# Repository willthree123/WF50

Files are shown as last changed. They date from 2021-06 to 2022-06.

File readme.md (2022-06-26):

# WF50

WF50 is a 50-keys split keyboard.

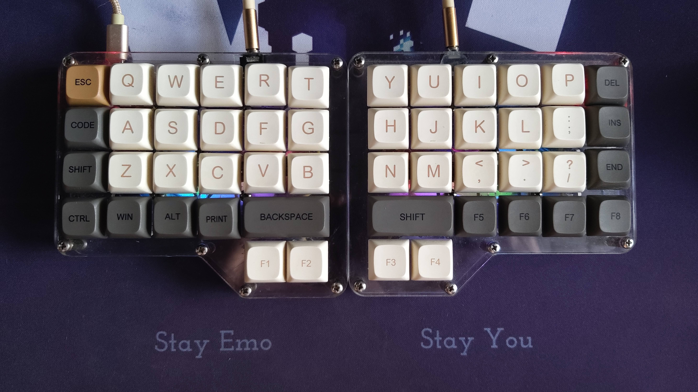
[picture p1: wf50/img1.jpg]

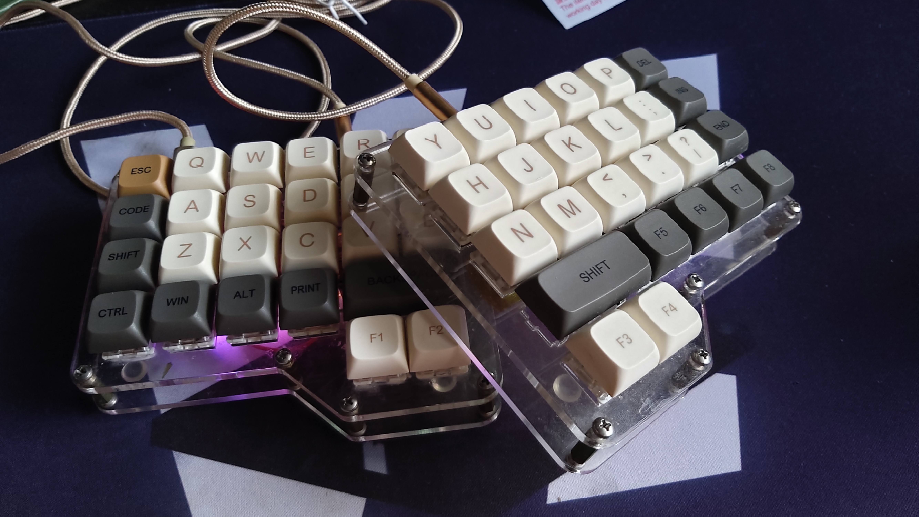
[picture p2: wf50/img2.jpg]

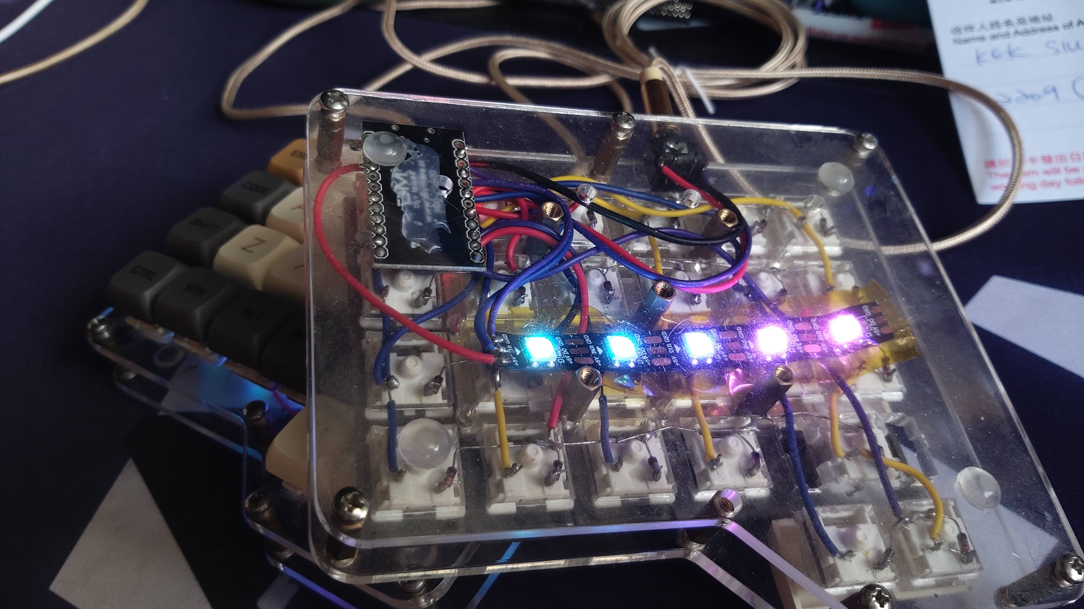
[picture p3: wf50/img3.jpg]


Keyboard Maintainer: [willthree123](https://github.com/willthree123/) Instagram: [@kok.sc_jesse](https://instagram.com/kok.sc_jesse)  
Hardware Supported: ProMicro

Make example for this keyboard (after setting up your build environment):

    qmk compile -kb handwired/wf50 -km via

---

# WF50P

WF50P is a PCB version of WF50(50-keys split keyboard).

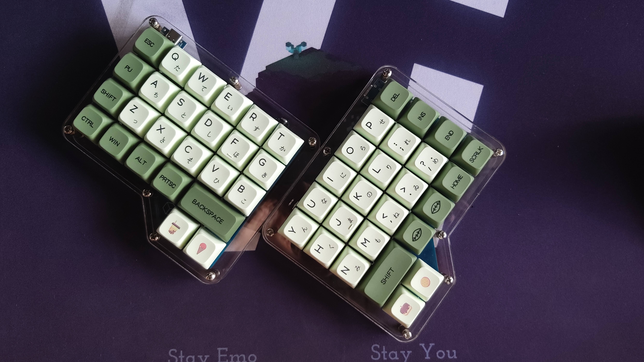
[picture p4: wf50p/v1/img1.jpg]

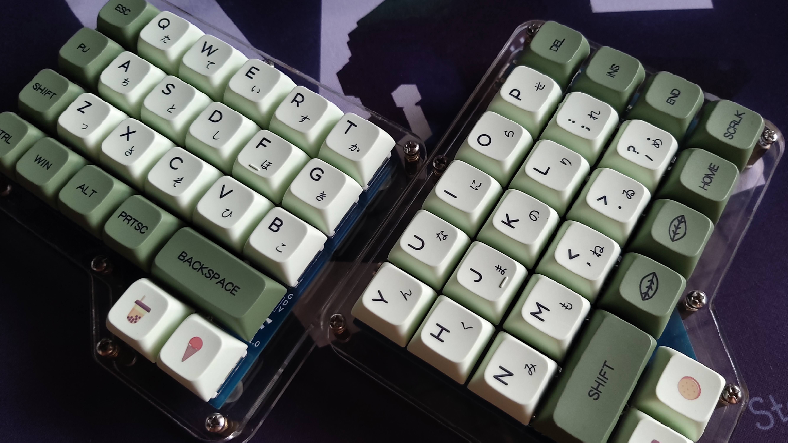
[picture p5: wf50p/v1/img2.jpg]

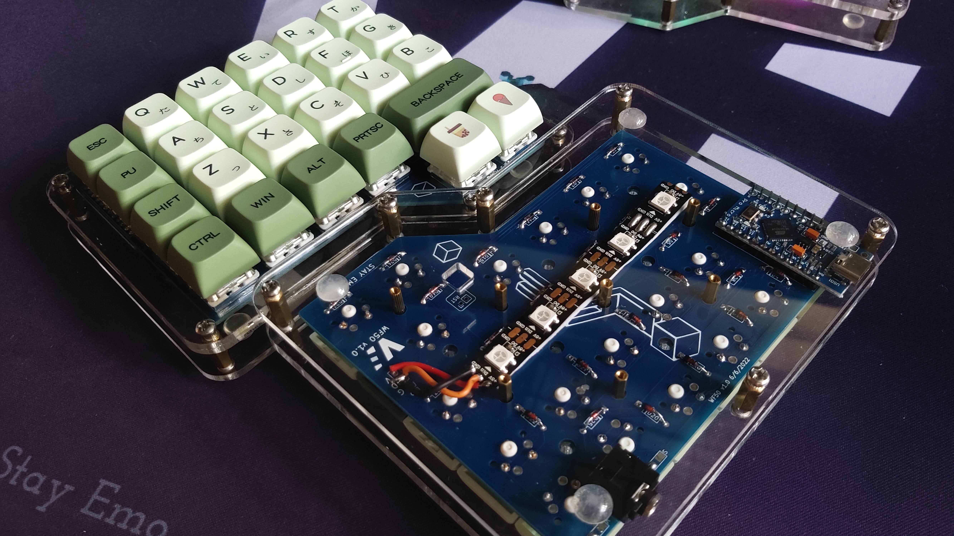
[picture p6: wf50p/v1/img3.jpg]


Keyboard Maintainer: [willthree123](https://github.com/willthree123/) Instagram: [@kok.sc_jesse](https://instagram.com/kok.sc_jesse)  
Hardware Supported: ProMicro

Make example for this keyboard (after setting up your build environment):

    qmk compile -kb wf50p -km via
---
See the [build environment setup](https://docs.qmk.fm/#/getting_started_build_tools) and the [make instructions](https://docs.qmk.fm/#/getting_started_make_guide) for more information. Brand new to QMK? Start with our [Complete Newbs Guide](https://docs.qmk.fm/#/newbs).

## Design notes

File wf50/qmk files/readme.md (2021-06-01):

- - -
### 1.2.1 [2021/6/1 14:34]

- Added "schematic.png"

### 1.2.0 [2021/5/31 04:08]

- All done

### 1.1.0 [2021/5/31 03:57]

- Added reset

### 1.0.0 [2021/5/30 23:32]

- First commit

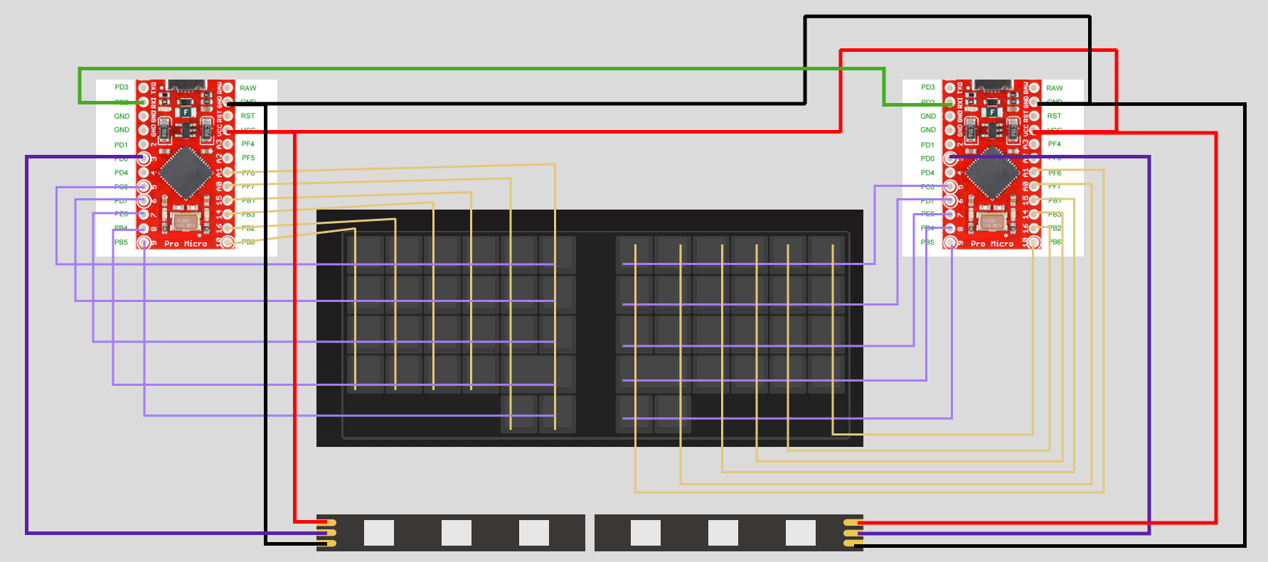
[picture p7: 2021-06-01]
wf50/schematic.png

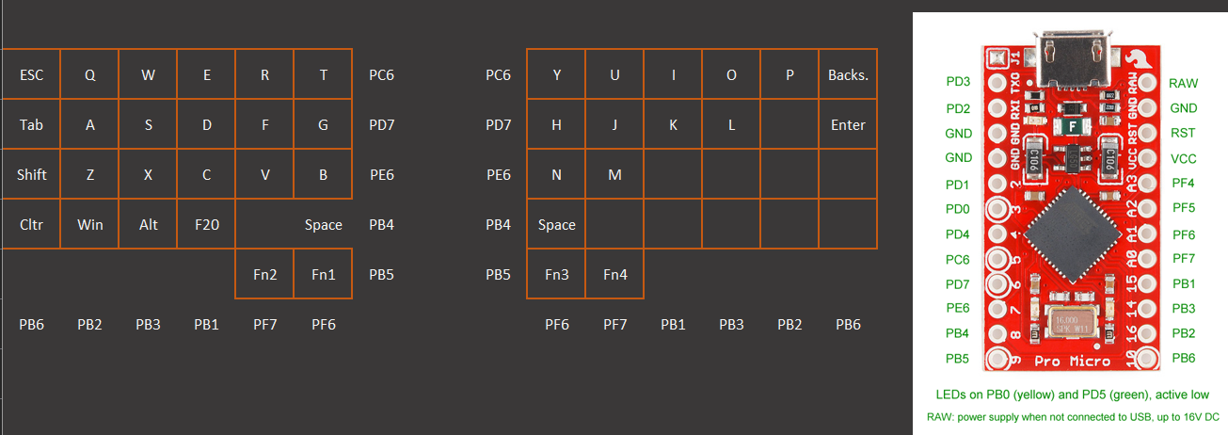
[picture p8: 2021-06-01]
wf50/martix.png

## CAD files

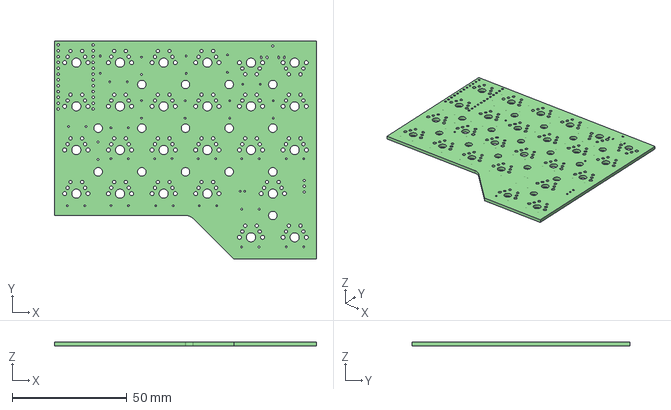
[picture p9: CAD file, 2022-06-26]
wf50p/v1/pcb/wf50_pcb.step
114.3 x 95.2 x 1.60 mm

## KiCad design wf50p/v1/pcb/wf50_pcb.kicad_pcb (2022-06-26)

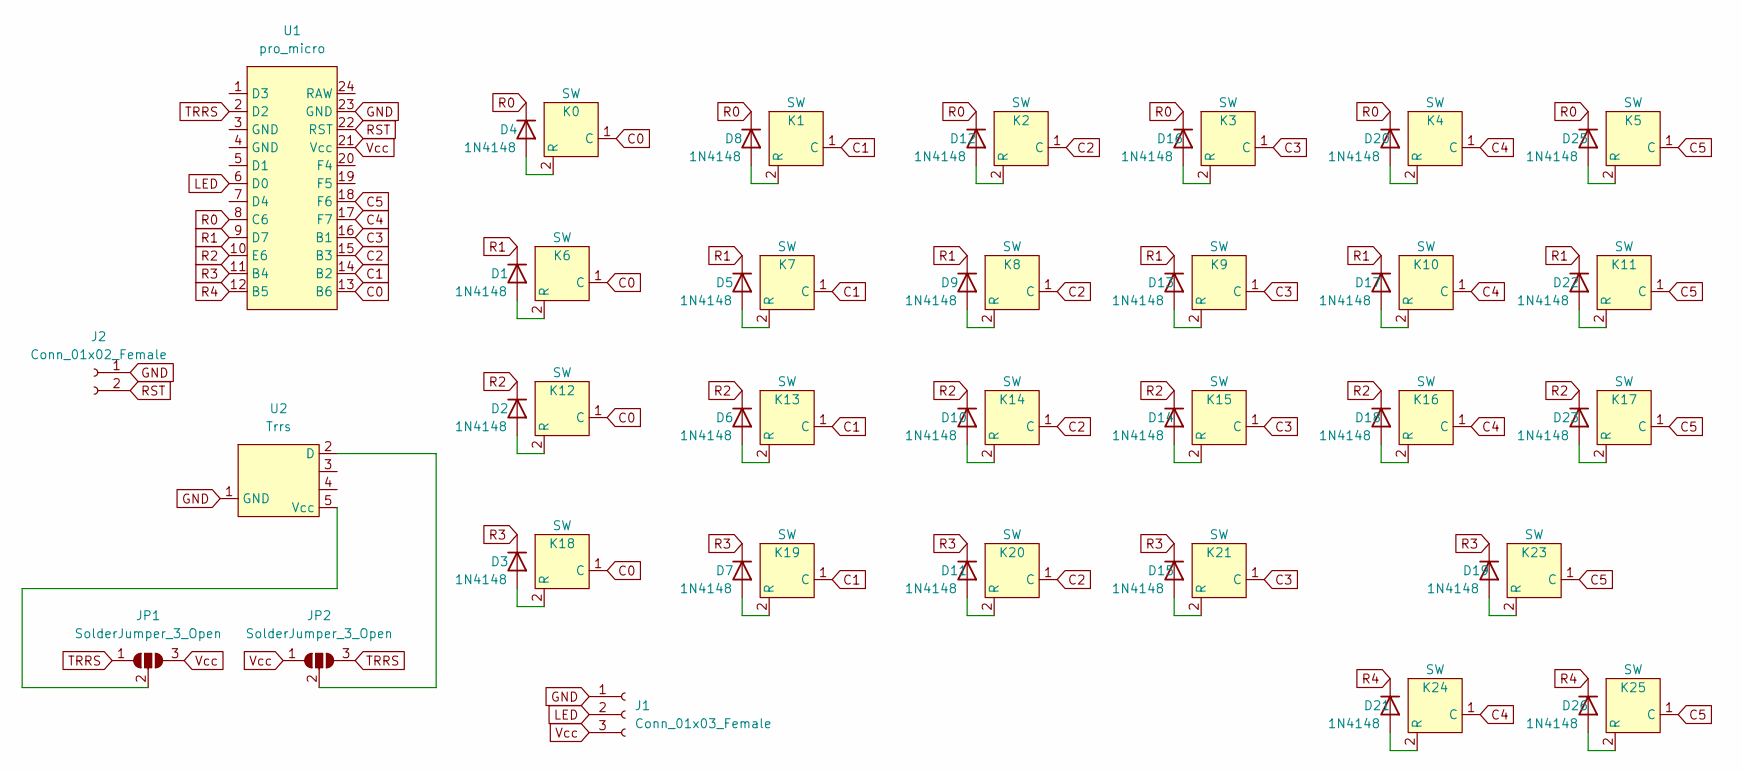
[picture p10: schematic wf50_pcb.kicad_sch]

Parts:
D1, D2, D3, D4, D5, D6, D7, D8, D9, D10, D11, D12, D13, D14, D15, D16, D17, D18, D19, D20, D21, D22, D23, D25, D26: 1N4148; D_DO-35_SOD27_P7.62mm_Horizontal
J1: Conn_01x03_Female; PinHeader_1x03_P2.54mm_Vertical
J2: Conn_01x02_Female; PinHeader_1x02_P2.00mm_Vertical
JP1, JP2: SolderJumper_3_Open; SolderJumper-3_P2.0mm_Open_TrianglePad1.0x1.5mm_NumberLabels
K0, K1, K2, K3, K4, K5, K6, K7, K8, K9, K10, K11, K12, K13, K14, K15, K16, K17, K18, K19, K20, K21, K23, K24, K25: SW; MXOnly-1U-user-split
U1: pro_micro; ProMicro-EnforcedTop
U2: Trrs; Trrs_user

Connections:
C0: K0.1 (C), K6.1 (C), K12.1 (C), K18.1 (C), U1.13 (B6)
C1: K1.1 (C), K7.1 (C), K13.1 (C), K19.1 (C), U1.14 (B2)
C2: K2.1 (C), K8.1 (C), K14.1 (C), K20.1 (C), U1.15 (B3)
C3: K3.1 (C), K9.1 (C), K15.1 (C), K21.1 (C), U1.16 (B1)
C4: K4.1 (C), K10.1 (C), K16.1 (C), K24.1 (C), U1.17 (F7)
C5: K5.1 (C), K11.1 (C), K17.1 (C), K23.1 (C), K25.1 (C), U1.18 (F6)
GND: J1.1, J2.1, U1.23 (GND), U2.1 (GND); also elsewhere on the board
LED: J1.2, U1.6 (D0); also elsewhere on the board
unnamed: D1.2 (A), K6.2 (R)
unnamed: D2.2 (A), K12.2 (R)
unnamed: D3.2 (A), K18.2 (R)
unnamed: D4.2 (A), K0.2 (R)
unnamed: D5.2 (A), K7.2 (R)
unnamed: D6.2 (A), K13.2 (R)
unnamed: D7.2 (A), K19.2 (R)
unnamed: D8.2 (A), K1.2 (R)
unnamed: D9.2 (A), K8.2 (R)
unnamed: D10.2 (A), K14.2 (R)
unnamed: D11.2 (A), K20.2 (R)
unnamed: D12.2 (A), K2.2 (R)
unnamed: D13.2 (A), K9.2 (R)
unnamed: D14.2 (A), K15.2 (R)
unnamed: D15.2 (A), K21.2 (R)
unnamed: D16.2 (A), K3.2 (R)
unnamed: D17.2 (A), K10.2 (R)
unnamed: D18.2 (A), K16.2 (R)
unnamed: D19.2 (A), K23.2 (R)
unnamed: D20.2 (A), K4.2 (R)
unnamed: D21.2 (A), K24.2 (R)
unnamed: D22.2 (A), K11.2 (R)
unnamed: D23.2 (A), K17.2 (R)
unnamed: D25.2 (A), K5.2 (R)
unnamed: D26.2 (A), K25.2 (R)
unnamed: JP1.2 (C), U2.5 (Vcc)
unnamed: JP2.2 (C), U2.2 (D)
R0: D4.1 (K), D8.1 (K), D12.1 (K), D16.1 (K), D20.1 (K), D25.1 (K), U1.8 (C6)
R1: D1.1 (K), D5.1 (K), D9.1 (K), D13.1 (K), D17.1 (K), D22.1 (K), U1.9 (D7)
R2: D2.1 (K), D6.1 (K), D10.1 (K), D14.1 (K), D18.1 (K), D23.1 (K), U1.10 (E6)
R3: D3.1 (K), D7.1 (K), D11.1 (K), D15.1 (K), D19.1 (K), U1.11 (B4)
R4: D21.1 (K), D26.1 (K), U1.12 (B5)
RST: J2.2, U1.22 (RST); also elsewhere on the board
TRRS: JP1.1 (A), JP2.3 (B), U1.2 (D2)
Vcc: J1.3, JP1.3 (B), JP2.1 (A), U1.21 (Vcc); also elsewhere on the board

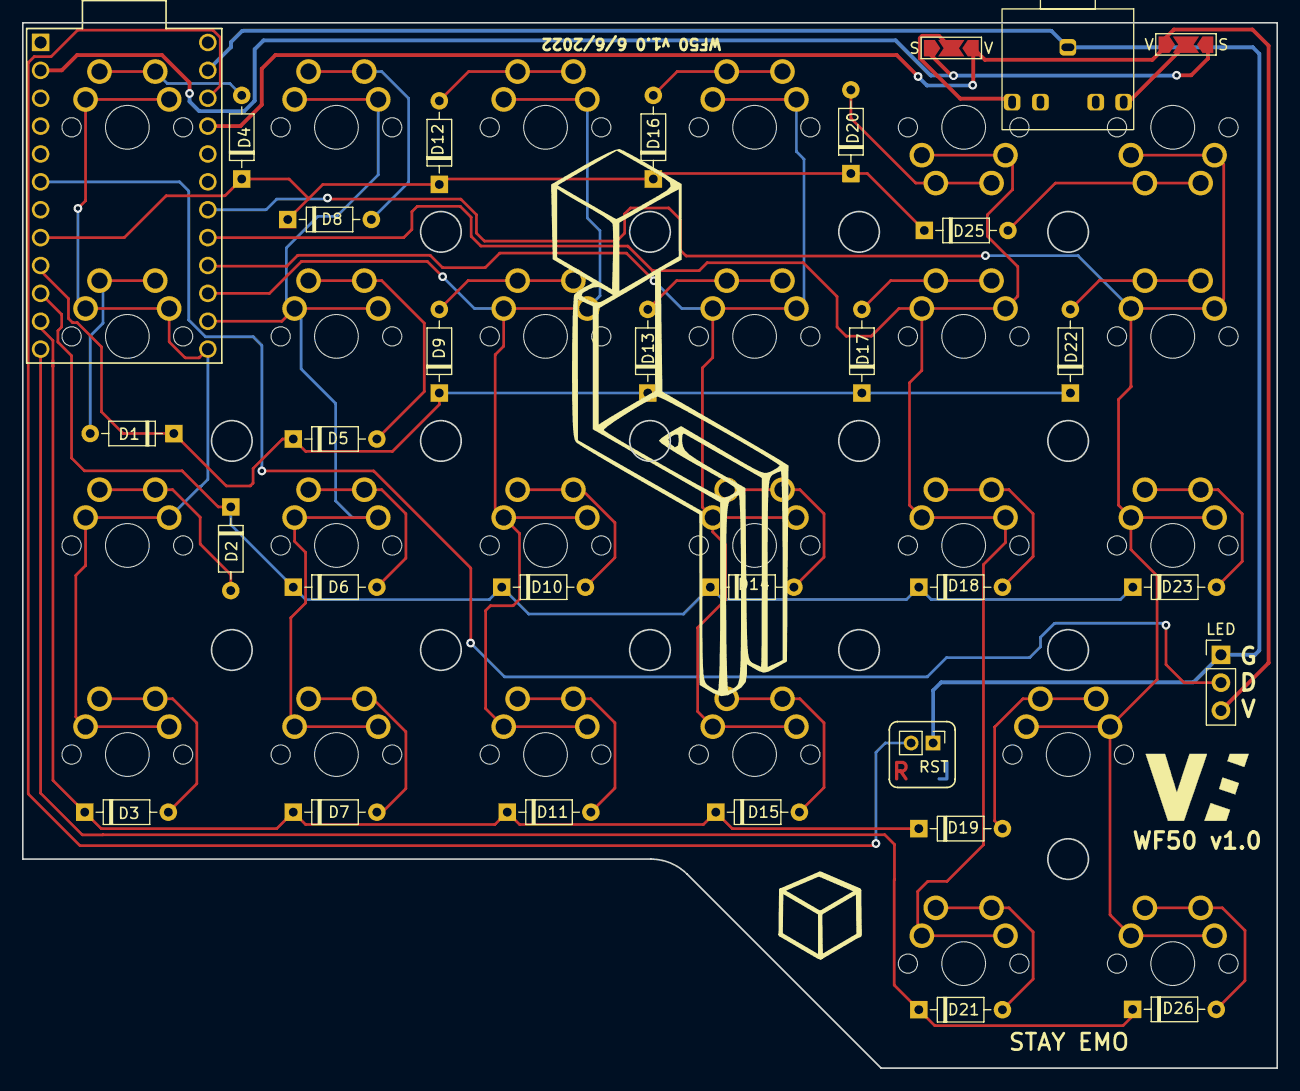
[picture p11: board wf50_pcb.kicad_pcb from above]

Board: 2 copper layers, 114.3 x 95.2 mm, 56 parts (0 on the bottom side), 43 nets.

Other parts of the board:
LED: Conn_01x03_Female; PinHeader_1x03_P2.54mm_Vertical
RST: Conn_01x02_Female; PinHeader_1x02_P2.00mm_Vertical

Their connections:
GND: LED.1, RST.1; also elsewhere on the board
LED: LED.2; also elsewhere on the board
RST: RST.2; also elsewhere on the board
Vcc: LED.3; also elsewhere on the board

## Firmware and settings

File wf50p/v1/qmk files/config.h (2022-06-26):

#pragma once
#include "config_common.h"

/* USB Device descriptor parameter */
#define VENDOR_ID       0x7766
#define PRODUCT_ID      0x0010
#define DEVICE_VER      0x0010
#define MANUFACTURER    willthree123
#define PRODUCT         wf50p
#define DESCRIPTION     "wf50p"

/* key matrix size */
#define MATRIX_ROWS 10
#define MATRIX_ROWS_PER_SIDE (MATRIX_ROWS / 2)
#define MATRIX_COLS 6

/* key matrix pins */
#define MATRIX_ROW_PINS { C6, D7, E6, B4, B5 }
#define MATRIX_COL_PINS { B6, B2, B3, B1, F7, F6 }
#define MATRIX_ROW_PINS_RIGHT { C6, D7, E6, B4, B5 }
#define MATRIX_COL_PINS_RIGHT { F6, F7, B1, B3, B2, B6 }
#define DIODE_DIRECTION COL2ROW
#define DEBOUNCE 5

#define USE_SERIAL
#define MASTER_LEFT
#define SERIAL_USE_MULTI_TRANSACTION
#define SOFT_SERIAL_PIN D2
#define DYNAMIC_KEYMAP_LAYER_COUNT 6

/* ws2812 RGB LED */
#define RGB_DI_PIN D0
#define RGBLED_NUM 10 
#define RGBLIGHT_SPLIT
#define RGBLIGHT_ANIMATIONS

#define USB_MAX_POWER_CONSUMPTION 500
